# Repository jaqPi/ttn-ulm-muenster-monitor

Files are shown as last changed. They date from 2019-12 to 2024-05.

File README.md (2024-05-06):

# Sensor/Node für's Münster-Monitoring

Aktuell im Test, Messaufbau und ein paar Infos: https://wiki.temporaerhaus.de/risssimulator16153

## Pin-Belegung

```
Münster-Platine              VL6180X      BME280       Pull-Up-Widerstände
---------------              -------      ------       -------------------

A4    SDA / Daten            4 / SDA      4 / SDA      *
A5    SCL / Takt             5 / SCL      3 / SCL      |   *
VCC   Versorgungsspannung    2 / VIN      1 / VIN      *   *
GND                          3 / GND      2 / GND
```

```
Adafruit Feather M0          VL6180X      BME280       Pull-Up-Widerstände
-------------------          -------      ------       -------------------

SDA    SDA / Daten           4 / SDA      4 / SDA      *
SCL    SCL / Takt            5 / SCL      3 / SCL      |   *
VCC   Versorgungsspannung    2 / VIN      1 / VIN      *   *
GND                          3 / GND      2 / GND
```

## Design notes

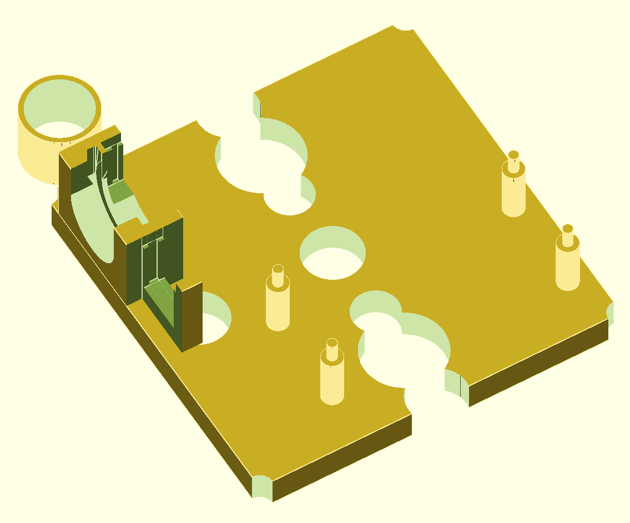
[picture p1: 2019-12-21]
3d-models/grundplatte_mit_halterungen.png

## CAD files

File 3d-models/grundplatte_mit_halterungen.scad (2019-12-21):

// Grundplatte mit Halterungen, für den Sensor des Münster-Monitorings

// mm

// X Position x-Achse
// Y Position y-Achse
// B Breite x-Achse
// H Höhe   z-Achse
// T Tiefe  y-Achse
// R Radius
// D Durchmesser


$fa = 0.1;
$fs = 0.1;

// PARAMETRIERUNG

e           = 0.4;  // Luft für Ungenauigkeiten des Druckers.


//Grundplatte gp mit Bohrungen:
gpUrsprX    = 0;
gpUrsprY    = 0;

gpB         = 70;
gpH         = 70;
gpT         = 6.2; //6.2

gpBohrungAktiv =  true;
gpBohrungX  = 0;
gpBohrungY  = 0;
gpBohrungD  = 5;
gpBohrungB  = gpB;//gpB - 2 * gpBohrungX;
gpBohrungH  = gpH;//gpH - 2 * gpBohrungY;


// Pins für Mikro-Controller pc:
pcX         = 20;  // Position Mittelpunkt Pin links unten
pcY         = 10;
// Maße für den Adafruit Feather:
pcB         = 45.6;  // Abstand Mittelpunkte Pins in x-Richtung
pcH         = 17.6;  // Abstand Mittelpunkte Pins in x-Richtung

pcBasisD    = 4;
pcBasisT    = 7 + 4 + gpT; // 7 mm für Dicke Akku, 4 mm Luft
pcPinD      = 2.5 - 1.5 * e;
pcPinT      = 4  + pcBasisT;  // Dicke PCB Feather ~ 1,6 mm



// Röhre als Durchlass r:

rH          = 12;
rDAussen    = 14;
rDickeWand  = 1;
rBasisD     = 4 + rDAussen;
rBasisH     = 1.0;
rHoeheUnterkanteBasisDUeberGP = 0;

// Scheibe zum Abschluss der Röhre s:

sDicke      = 1;
rHalterungBasisH = rBasisH + sDicke + 1.5 * e;
rHalterungBasisH = sDicke + 1.5 * e;


// Break out boards bob:

bobHoeheUnterkanteUeberGP = 4;
bobSteckerT = 2.6;
babAbstaendeInHalterung = 2;


// BME280, Billo-Breakoutboard bobBME280:

bobBME280Breite             = 10.5 + e;
bobBME280Dicke              = 1.55 + e; // Dicke PCB bobBME280 ~ 1,57 mm
bobBME280HoeheBisStecker    = 11;
bobBME280TiefeFuge          = 1 - e;
bobVME280X                  = 4;      // relativ zum Sensorhalterblock
//bobVME280Y                = bobVL6180XY + bobVL6180XBreite + babAbstaendeInHalterung;
bobVME280Y                  = babAbstaendeInHalterung + 0;
bobVME280Z                  = gpT + bobHoeheUnterkanteUeberGP - (gpT - 1) - 1;


// VL6180X, Pololu-Breakoutboard bobVL6180X:

bobVL6180XBreite            = 17.8 + e;
bobVL6180XDicke             = 0.9 + e;
bobVL6180XHoeheBisStecker   = 10;
bobVL6180XHoehe             = bobVL6180XHoeheBisStecker + bobSteckerT;
bobVL6180XTiefeFuge         = 1 - e ;       // Dicke PCB bobVL6180X ~ 1 mm
bobVL6180XX                 = 9;
//bobVL6180XY               = babAbstaendeInHalterung + 0;
bobVL6180XY                 = bobVME280Y + bobBME280Breite + babAbstaendeInHalterung;
bobVL6180XZ                 = gpT + bobHoeheUnterkanteUeberGP - (gpT - 1);


// Block, um in der Sensorhalterung Aussparungen für die Stecker zu schaffen

mBreakoutboardSteckerBlockT = 10;
mBreakoutboardSteckerBlockB = 20;
mBreakoutboardSteckerBlockOffsetX = -2; // Für Überstand Pins/Lötkegel


// Block für Halterung der Sensoren sb:

sbB     = 11;
sbH     = bobVL6180XBreite + bobBME280Breite + 3 * babAbstaendeInHalterung;
sbT     = gpT + bobHoeheUnterkanteUeberGP + bobVL6180XHoehe - (gpT - 1);
sbX     = 0;
sbY     = 48 - ( 2 * ( 2 + e ) + bobBME280Breite + (rBasisD - rDAussen) / 2);
sbZ     = gpT - 0.2;






// AUFBAU


// Grundplatte mit Pins:

module bohrung (x, y, z = 0,
                h = gpT * 4, d = gpBohrungD, centered = true
                ) {
    translate([x, y, z]) {
        cylinder(h = h, d = d, center = centered);
    }
}

module pin (x, y, z = 0) {
    translate([x, y, z]) {
        union () {
            cylinder(h = pcBasisT, d = pcBasisD);
            cylinder(h = pcPinT, d = pcPinD);
        }
    }
}


difference () {

    cube([gpB, gpH, gpT]);

    if (gpBohrungAktiv) {
        bohrung(gpBohrungX             , gpBohrungY);
        bohrung(gpBohrungX + gpBohrungB, gpBohrungY);
        bohrung(gpBohrungX             , gpBohrungY + gpBohrungH);
        bohrung(gpBohrungX + gpBohrungB, gpBohrungY + gpBohrungH);
    }
    
    bohrung(x = 35, y = 1, d = 10 + 3 * e);
    bohrung(x = 35, y = 70 - 1, d = 10 + 3 * e);
    translate([35, 0, 0]) {
        cube([10 + 2 * e, (10 + 3 * e) / 2, gpT * 4], center = true);
    }
    translate([35, 70, 0]) {
        cube([10 + 2 * e, (10 + 3 * e) / 2, gpT * 4], center = true);
    }
    
    bohrung(x = 35, y = 5 + 6.8,          d = 15 + e);
    bohrung(x = 35, y = 70 - (5 + 6.8),   d = 15 + e);
    
    bohrung(x = 35, y = 35 - 14, d = 7.5 + 3 * e);
    bohrung(x = 35, y = 35 + 14, d = 7.5 + 3 * e);
    
    bohrung(x = 35,         y = 35, d = 10.2 + 2 * e);
    bohrung(x = 35 - 26,    y = 35, d = 10.2 + 2 * e);
    
    translate ([14, 14 ,-1]) {
        cube([12, 13, 2 + 1]);
        translate ([0, 29 , 0]) {
            cube([12, 13, 2 + 1]);
        }
    }
    
}

pin(pcX      , pcY);
pin(pcX + pcB, pcY);
pin(pcX      , pcY + pcH);
pin(pcX + pcB, pcY + pcH);



// Röhre

module roehre ( x, y, z, 
                hoehe,
                durchmesserAussen,
                dickeWand,
                basisDurchmesser,
                basisHoehe,
                gefuellt = false,
                basis = true) {

    zentriert = true;
    translate([x, y, z]) {
        difference () {
            union () {
                translate ([0, 0, hoehe / 2]) {
                    cylinder(h = hoehe, d = durchmesserAussen, center = zentriert);
                }
                if (basis) {
                    translate ([0, 0, basisHoehe / 2]) {
                        cylinder(h = basisHoehe, d = basisDurchmesser, center = zentriert);
                    }
                }
            }
            if (! gefuellt) {
                cylinder(h = hoehe * 4, d = durchmesserAussen - 2 * dickeWand, center = zentriert);
            }
        }
    }
}



module roehreAussparung () {
    translate ([0, rBasisD / 2, rBasisD / 2 + rHoeheUnterkanteBasisDUeberGP]) {
    union () {
        linear_extrude (20) {
            projection () {
                rotate ([0, -90, 0 ]) {
                    roehre (0, 0, 0,
                            rH, rDAussen, rDickeWand, rBasisD, rHalterungBasisH,
                            gefuellt = true);
                }
            }
        }
        rotate ([0, -90, 0 ]) {
            roehre (0, 0, 0,
                    rH, rDAussen, rDickeWand, rBasisD, rHalterungBasisH,
                    gefuellt = true);
        }
    }
}
}

roehre (rBasisD / 2, gpH + rBasisD / 2 + 1 , 0,
        rH, rDAussen, rDickeWand, rBasisD, rBasisH,
        gefuellt = false, basis = false);

//roehre (rBasisD * 1.5, gpH + rBasisD / 2 + 1 , 0,
//        rH, rDAussen, rDickeWand, rBasisD, rBasisH,
//        gefuellt = false);




// Sensorhalterung

module breakoutboard (breite, dicke, hoeheBisStecker, breiteFuge, x, y, z) {
    translate ([x, y, z]) {
    union () {
        cube([dicke, breite, hoeheBisStecker+mBreakoutboardSteckerBlockT]);
        translate ([mBreakoutboardSteckerBlockOffsetX, 0, hoeheBisStecker]) {
            cube([mBreakoutboardSteckerBlockB, breite, mBreakoutboardSteckerBlockT]);
        }
        translate ([mBreakoutboardSteckerBlockOffsetX, breiteFuge, 0]) {
            cube([  mBreakoutboardSteckerBlockB,
                    breite - 2 * breiteFuge,
                    hoeheBisStecker + mBreakoutboardSteckerBlockT
            ]);
        }
    }
    }
}


translate([sbX, sbY, sbZ]) {
difference () {
    
    cube([sbB, sbH, sbT]);
    
    breakoutboard(bobVL6180XBreite, bobVL6180XDicke, bobVL6180XHoeheBisStecker, bobVL6180XTiefeFuge, bobVL6180XX, bobVL6180XY, bobVL6180XZ);
    
    breakoutboard(bobBME280Breite, bobBME280Dicke, bobBME280HoeheBisStecker, bobBME280TiefeFuge, bobVME280X, bobVME280Y, bobVME280Z);    
    
    translate ([bobVL6180XX - ( 1 + abs(mBreakoutboardSteckerBlockOffsetX)) ,
                bobVL6180XY + (bobVL6180XBreite - rBasisD) / 2 ,
                1
                ]) {
        roehreAussparung ();
        translate ([-rHalterungBasisH, rBasisD, 0]) {
            rotate ([180, 180, 0]) {
                roehreAussparung ();
            }
        }

    }
    
    // Materialeinsparungen:
    translate([-1 , bobVME280Y - babAbstaendeInHalterung - e, -1]) {
        cube([  bobVME280X + mBreakoutboardSteckerBlockOffsetX + 2.01,
                bobBME280Breite + babAbstaendeInHalterung + 0.01 + e,
                sbT * 2
            ]);
        translate([8, 0, -1]) {
            cube([  bobVME280X + mBreakoutboardSteckerBlockOffsetX + 3.01,
                bobBME280Breite + babAbstaendeInHalterung + 0.01 + e,
                sbT * 2
            ]);
        }
    }
    
}
}

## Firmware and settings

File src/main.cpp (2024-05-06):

/*
Code is based on the the OTAA example of the arduino-lmic library

 * Copyright (c) 2015 Thomas Telkamp and Matthijs Kooijman
 * Copyright (c) 2018 Terry Moore, MCCI

which is licensed under the MIT license
https://github.com/mcci-catena/arduino-lmic/blob/master/examples/ttn-otaa/ttn-otaa.ino
*/

#include "arduino_lmic.h"
#include <hal/hal.h>
#include <Wire.h>
#include <SPI.h>
#include <Adafruit_Sensor.h>
#include <Adafruit_BME280.h>
#include <VL6180X.h>
#include "measurements.h"
#include "sensors.h"
#include <Statistics.h>


#include <Credentials.h> // TODO

// #define SINGLE_VALUES
const uint8_t numberOfMeasurements = 50; // max 255!

VL6180X sensorVL6180X;
const SensorConfig configInterleaved = { INTERLEAVED, MANUAL, 30, 50, 500};
const TofSensor tofSensor = TofSensor { sensorVL6180X, configInterleaved, 0, 0x29 };

#ifdef DEBUG
  #define print(x) Serial.print(x);
  #define println(x) Serial.println(x);
#else
  #define print(x)
  #define println(x)
#endif

Adafruit_BME280 bme; // I2C, depending on your BME, you have to use address 0x77 (default) or 0x76, see below


// These callbacks are only used in over-the-air activation, so they are
// left empty here (we cannot leave them out completely unless
// DISABLE_JOIN is set in arduino-lmic/project_config/lmic_project_config.h,
// otherwise the linker will complain).
void os_getArtEui (u1_t* buf) { memcpy_P(buf, APPEUI, 8);}
void os_getDevEui (u1_t* buf) { memcpy_P(buf, DEVEUI, 8);}
void os_getDevKey (u1_t* buf) {  memcpy_P(buf, APPKEY, 16);}

static osjob_t sendjob;

const unsigned TX_INTERVAL = 5*60; // in seconds
const int SLEEP_CYCLES = (int) (TX_INTERVAL / 8);


// Pin mapping
#ifdef MINSTER_NODE
// Pin mapping for Minster Node
const lmic_pinmap lmic_pins = {
        .nss = 10, // ulm node 10
        .rxtx = LMIC_UNUSED_PIN,
        .rst = LMIC_UNUSED_PIN,
        .dio = {4, 5, 6}, // TTN Ulm Minster node {4, 5 ,6}
};
#elif FEATHER_M0
// Pin mapping for Adafruit Feather M0 LoRa
const lmic_pinmap lmic_pins = {
    .nss = 8,
    .rxtx = LMIC_UNUSED_PIN,
    .rst = 4,
    .dio = {3, 6, LMIC_UNUSED_PIN},
    .rxtx_rx_active = 0,
    .rssi_cal = 8,              // LBT cal for the Adafruit Feather M0 LoRa, in dB
    .spi_freq = 8000000,
};
#endif

void printValues() {
    // print("Temperature = ");
    // print(bme.readTemperature());
    // println(" *C");

    // print("Pressure = ");

    // print(bme.readPressure());
    // println(" hPa");

    // print("Humidity = ");
    // print(bme.readHumidity());
    // println(" %");

    // println();
}

float measureBatteryVoltage() {
    float measuredvbat = analogRead(A0);
    measuredvbat *= 2;    // we divided by 2, so multiply back
    measuredvbat *= 3.3;  // Multiply by 3.3V, our reference voltage
    measuredvbat /= 1024; // convert to voltage
    return measuredvbat;
}

void do_send(osjob_t* j){
    // Check if there is not a current TX/RX job running
    if (LMIC.opmode & OP_TXRXPEND) {
      println(F("OP_TXRXPEND, not sending"));
    } else {
        // temp -> 2 byte
        // pressure -> 2 byte
        // humidity -> 2 byte
        // distance -> 2 byte
        // distanceMedian -> 2 byte
        // distanceSD -> 2 byte
        // distanceSucc -> 1 byte
        // ambientLight -> 2 byte
        // ambientLightMedian -> 2 byte
        // ambientLightSD -> 2 byte
        // ambietnLightSucc -> 1 byte
        // batteryVoltage -> 2 byte

        // sum -> 22 byte
        byte payload[22];

        // Only needed in forced mode. Force update of BME values
        bme.takeForcedMeasurement();

        #ifdef DEBUG
          printValues();
        #endif

        // temp
        int temp = round(bme.readTemperature() * 100);
        payload[0] = highByte(temp);
        payload[1] = lowByte(temp);

        // pressure
        int pressure = round(bme.readPressure()/100);
        payload[2] = highByte(pressure);
        payload[3] = lowByte(pressure);

        // humidity
        int humidity = round(bme.readHumidity() * 100);
        payload[4] = highByte(humidity);
        payload[5] = lowByte(humidity);

        measurement_t currentMeasurement = measureDistanceAndAmbientLight(&tofSensor, numberOfMeasurements);

        // distance
        int meanDistance = round(currentMeasurement.distance.mean * 100);
        payload[6] = highByte(meanDistance);
        payload[7] = lowByte(meanDistance);

        int standardDeviationDistance = round(currentMeasurement.distance.standardDeviation * 100);
        payload[8] = highByte(standardDeviationDistance);
        payload[9] = lowByte(standardDeviationDistance);

        int medianDistance = round(currentMeasurement.distance.median * 100);
        payload[10] = highByte(medianDistance);
        payload[11] = lowByte(medianDistance);

        payload[12] = currentMeasurement.successfulMeasurementsDistance;

        // ambientLight
        int meanAmbientLight = round(currentMeasurement.light.mean * 100);
        payload[13] = highByte(meanAmbientLight);
        payload[14] = lowByte(meanAmbientLight);

        int standardDeviationAmbientLight = round(currentMeasurement.light.standardDeviation * 100);
        payload[15] = highByte(standardDeviationAmbientLight);
        payload[16] = lowByte(standardDeviationAmbientLight);

        int medianLight = round(currentMeasurement.light.median * 100);
        payload[17] = highByte(medianLight);
        payload[18] = lowByte(medianLight);

        payload[19] = currentMeasurement.successfulMeasurementsAmbientLight;

        //int batteryVoltage = round(measureBatteryVoltage() * 100);
        // temporary set battery voltage to zero
        int batteryVoltage = 0;
        payload[20] = highByte(batteryVoltage);
        payload[21] = lowByte(batteryVoltage);


        LMIC_setTxData2(1, (uint8_t*)payload, sizeof(payload), 0);
        println(F("Pckt qd"));
    }
}

void onEvent (ev_t ev) {
    // print(os_getTime());
    // print(": ");
    print(os_getTime());
    println(": ");
    switch(ev) {
#ifndef MINSTER_NODE
        case EV_SCAN_TIMEOUT:
            println(F("EV_SCAN_TIMEOUT"));
            break;
        case EV_BEACON_FOUND:
            println(F("EV_BEACON_FOUND"));
            break;
        case EV_BEACON_MISSED:
            println(F("EV_BEACON_MISSED"));
            break;
        case EV_BEACON_TRACKED:
            println(F("EV_BEACON_TRACKED"));
            break;
        case EV_JOINING:
            println(F("EV_JOINING"));
            break;
        case EV_JOINED:
            println(F("EV_JOINED"));
            break;
        /*
        || This event is defined but not used in the code. No
        || point in wasting codespace on it.
        ||
        || case EV_RFU1:
        ||     Serial.println(F("EV_RFU1"));
        ||     break;
        */
        case EV_JOIN_FAILED:
            println("EV_JOIN_FAILED");
            break;
        case EV_REJOIN_FAILED:
            println("EV_REJOIN_FAILED");
            break;
#endif
        case EV_TXCOMPLETE:
            println("EV_TXCOMPLETE");
#ifndef MINSTER_NODE
            if (LMIC.txrxFlags & TXRX_ACK)
              println("Rcvd ack");
            if (LMIC.dataLen) {
              println("Received ");
              println(LMIC.dataLen);
              println(" bytes of payload");
            }
#endif
            // println(F("EV_TXCOMPLETE"));
            // if (LMIC.txrxFlags & TXRX_ACK)
            //     println(F("Received ack"));
            // if (LMIC.dataLen) {
            //     println(F("Received "));
            //     println(LMIC.dataLen);
            //     println(F(" bytes of payload"));
            // }

            // Now preparing to go into sleep mode. The LMIC library already
            // powers down the RFM95, see
            // https://www.thethingsnetwork.org/forum/t/how-to-put-rfm95-to-sleep/9427

            // Following code is adapted by
            // https://github.com/rocketscream/MiniUltraPro/blob/master/ttn-otaa-sleep.ino

            // Ensure all debugging messages are sent before sleep
            #ifdef DEBUG
              Serial.flush();
            #endif

            // Going into sleep for more than 8 s – any better idea?
            // disabled due to sensor vulnerability to voltage
            //for(int i = 0; i < SLEEP_CYCLES; i++) {
            //  LowPower.powerDown(SLEEP_8S, ADC_OFF, BOD_OFF);
            //}

            // Schedule next transmission to be immediately after this
            os_setTimedCallback(&sendjob, os_getTime() + sec2osticks(TX_INTERVAL), do_send);

            break;
#ifndef MINSTER_NODE
        case EV_LOST_TSYNC:
            println(F("EV_LOST_TSYNC"));
            break;
        case EV_RESET:
            println(F("EV_RESET"));
            break;
        case EV_RXCOMPLETE:
            // data received in ping slot
            println(F("EV_RXCOMPLETE"));
            break;
        case EV_LINK_DEAD:
            println(F("EV_LINK_DEAD"));
            break;
        case EV_LINK_ALIVE:
            println(F("EV_LINK_ALIVE"));
            break;
        /*
        || This event is defined but not used in the code. No
        || point in wasting codespace on it.
        ||
        || case EV_SCAN_FOUND:
        ||    Serial.println(F("EV_SCAN_FOUND"));
        ||    break;
        */
        case EV_TXSTART:
            println(F("EV_TXSTART"));
            break;
        case EV_TXCANCELED:
            println(F("EV_TXCANCELED"));
            break;
        case EV_RXSTART:
            /* do not print anything -- it wrecks timing */
            break;
        case EV_JOIN_TXCOMPLETE:
            println(F("EV_JOIN_TXCOMPLETE: no JoinAccept"));
            break;
        default:
            print(F("Unknown event: "));
            println((unsigned) ev);
            break;
#endif
    }
}

void scanI2C() {
  println("I2C scanner. Scanning ...");
  byte count = 0;


  for (byte i = 1; i < 120; i++)
  {

    Wire.beginTransmission (i);
    if (Wire.endTransmission () == 0)
    {
      print("Found address: ");
      print(i);
      print(" (0x");
      print(i);
      println(")");
      count++;
      delay (1);  // maybe unneeded?
    } // end of good response
  } // end of for loop
  println("Done.");
  print("Found ");
  print(count);
  println(" device(s).");
}

void setup() {
    #ifdef DEBUG
      Serial.begin(9600);
      while(!Serial);
    #endif
    println(F("Strtng"));

    Wire.begin();
    delay(5000);



    // Switch off on board LED
    pinMode(LED_BUILTIN, OUTPUT);
    digitalWrite(LED_BUILTIN, LOW);

    #ifdef DEBUG
      scanI2C();
    #endif
    

    // Setup BME280, use address 0x77 (default) or 0x76
    if (!bme.begin(0x76)) {
      println(F("noBME"));
      while (1);
    }

    // Set BME in force mode to reduce power consumption
    // force mode = measure, store results, and go into sleep mode
    // until next measurement, see
    // - http://tinkerman.cat/low-power-weather-station-bme280-moteino/
    // - https://github.com/adafruit/Adafruit_BME280_Library/blob/master/examples/advancedsettings/advancedsettings.ino
    bme.setSampling(Adafruit_BME280::MODE_FORCED,
                    Adafruit_BME280::SAMPLING_X1, // temperature
                    Adafruit_BME280::SAMPLING_X1, // pressure
                    Adafruit_BME280::SAMPLING_X1, // humidity
                    Adafruit_BME280::FILTER_OFF   );


      tofSensor.sensor.init();
      tofSensor.sensor.configureDefault();

      // Reduce range max convergence time and ALS integration
      // time to 30 ms and 50 ms, respectively, to allow 10 Hz
      // operation (as suggested by table "Interleaved mode
      // limits (10 Hz operation)" in the datasheet).
      tofSensor.sensor.writeReg(VL6180X::SYSRANGE__MAX_CONVERGENCE_TIME, tofSensor.config.rangeMaxConvergenceTime);
      tofSensor.sensor.writeReg16Bit(VL6180X::SYSALS__INTEGRATION_PERIOD, tofSensor.config.alsMaxIntegrationPeriod);
      tofSensor.sensor.setTimeout(tofSensor.config.timeout);

      // stop continuous mode if already active
      tofSensor.sensor.stopContinuous();
      // in case stopContinuous() triggered a single-shot
      // measurement, wait for it to complete
      delay(300);

      if(tofSensor.config.calibrationMode == MANUAL) {
        // disable auto calibrate (to do it manually before every series)
        tofSensor.sensor.writeReg(VL6180X::SYSRANGE__VHV_REPEAT_RATE, 0x00);    
        // calibrate single time (actually the sensor should have done it during start up)
        tofSensor.sensor.writeReg(VL6180X::SYSRANGE__VHV_RECALIBRATE, 0x01);   
      }

      println(", configuration completed");

     // LMIC init
    os_init();
    // Reset the MAC state. Session and pending data transfers will be discarded.
    LMIC_reset();


    LMIC_setClockError(MAX_CLOCK_ERROR * 20 / 100);

    // Disable link check validation
    LMIC_setLinkCheckMode(0);

    // TTN uses SF9 for its RX2 window.
    LMIC.dn2Dr = DR_SF9;

    // Set data rate and transmit power for uplink
    LMIC_setDrTxpow(DR_SF7,14);

    // Start job
    do_send(&sendjob);
}

void loop() {
    os_runloop_once();
}

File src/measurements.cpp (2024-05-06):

#include "measurements.h"

measurement_t measureDistanceAndAmbientLight(const TofSensor *tofSensor, uint8_t numberOfMeasurements) {
    if(tofSensor->config.measureMode == INTERLEAVED) {
        return measureDistanceAndAmbientLightInterleaved(tofSensor, numberOfMeasurements);
    }
    else {
        return measureDistanceAndAmbientLightOneByOne(tofSensor, numberOfMeasurements);
    }
}

measurement_t measureDistanceAndAmbientLightInterleaved(const TofSensor *tofSensor, uint8_t numberOfMeasurements) {
    uint16_t measurementSeriesDistance[numberOfMeasurements];
    uint16_t measurementSeriesAmbientLight[numberOfMeasurements];

    Serial.print("Start interleaved measurement using ToF-Sensor ");
    Serial.print(tofSensor->i2cAddress);
    Serial.print(", #Measurement: ");
    Serial.println(numberOfMeasurements);

    // calibrate sensor in terms of temperature manually
    if(tofSensor->config.calibrationMode == MANUAL) {
        tofSensor->sensor.writeReg(VL6180X::SYSRANGE__VHV_RECALIBRATE, 0x01);    
    }


    tofSensor->sensor.startInterleavedContinuous();
    uint8_t successfulMeasurementsDistance = 0;
    uint8_t successfulMeasurementsAmbientLight = 0;

    for (uint8_t i = 0; i < numberOfMeasurements; i++) {
        // Ambient Light
        uint16_t currentAmbientLight = tofSensor->sensor.readAmbientContinuous();
        if (!tofSensor->sensor.timeoutOccurred()) {
            measurementSeriesAmbientLight[successfulMeasurementsAmbientLight] = currentAmbientLight;
            successfulMeasurementsAmbientLight += 1;

            #ifdef SINGLE_VALUES
                // Print current value to Serial
                if(i == numberOfMeasurements - 1) {
                    Serial.println(currentAmbientLight);
                }
                else {
                    Serial.print(currentAmbientLight);
                    Serial.print(",");
                }
            #endif
        }

        // Distance
        uint16_t currentDistance = (uint16_t) tofSensor->sensor.readRangeContinuous();
        if (!tofSensor->sensor.timeoutOccurred()) {
            measurementSeriesDistance[successfulMeasurementsDistance] = currentDistance;
            successfulMeasurementsDistance += 1;

            #ifdef SINGLE_VALUES
                // Print current value to Serial
                if(i == numberOfMeasurements - 1) {
                    Serial.println(currentDistance);
                }
                else {
                    Serial.print(currentDistance);
                    Serial.print(",");
                }
            #endif
        }
    }
    tofSensor->sensor.stopContinuous();

    stats_t statsAmbientLight = calcStats(successfulMeasurementsAmbientLight, measurementSeriesAmbientLight, numberOfMeasurements);
    stats_t statsDistance = calcStats(successfulMeasurementsDistance, measurementSeriesDistance, numberOfMeasurements);



    Serial.print("DistSucc: ");
    Serial.print(successfulMeasurementsDistance);
    Serial.print("/");
    Serial.print(numberOfMeasurements);
    Serial.println();

    Serial.print("DistM: ");
    Serial.print(statsDistance.mean);
    Serial.println();

    Serial.print("DistMD: ");
    Serial.print(statsDistance.median);
    Serial.println();

    Serial.print("DistSD: ");
    Serial.print(statsDistance.standardDeviation);
    Serial.println();


    Serial.print("ALSsuc: ");
    Serial.print(successfulMeasurementsAmbientLight);
    Serial.print("/");
    Serial.print(numberOfMeasurements);
    Serial.println();

    Serial.print("ALSM: ");
    Serial.print(statsAmbientLight.mean);
    Serial.println();

    Serial.print("ALSMD: ");
    Serial.print(statsAmbientLight.median);
    Serial.println();

    Serial.print("ALSSD: ");
    Serial.print(statsAmbientLight.standardDeviation);
    Serial.println();

	measurement_t measurement = { statsDistance, statsAmbientLight, successfulMeasurementsDistance, successfulMeasurementsAmbientLight };

  return measurement;
}

measurement_t measureDistanceAndAmbientLightOneByOne(const TofSensor *tofSensor, uint8_t numberOfMeasurements) {
    uint16_t measurementSeriesDistance[numberOfMeasurements];
    uint16_t measurementSeriesAmbientLight[numberOfMeasurements];

    Serial.print("Start ony-by-one measurement using ToF-Sensor ");
    Serial.print(tofSensor->i2cAddress);
    Serial.print(", #Measurement: ");
    Serial.println(numberOfMeasurements);

    // calibrate sensor in terms of temperature manually
    if(tofSensor->config.calibrationMode == MANUAL) {
        tofSensor->sensor.writeReg(VL6180X::SYSRANGE__VHV_RECALIBRATE, 0x01);    
    }


    tofSensor->sensor.startAmbientContinuous();
    uint8_t successfulMeasurementsAmbientLight = 0;

    for (uint8_t i = 0; i < numberOfMeasurements; i++) {
        // Ambient Light
        uint16_t currentAmbientLight = tofSensor->sensor.readAmbientContinuous();
        if (!tofSensor->sensor.timeoutOccurred()) {
            measurementSeriesAmbientLight[successfulMeasurementsAmbientLight] = currentAmbientLight;
            successfulMeasurementsAmbientLight += 1;

            #ifdef SINGLE_VALUES
                // Print current value to Serial
                if(i == numberOfMeasurements - 1) {
                    Serial.println(currentAmbientLight);
                }
                else {
                    Serial.print(currentAmbientLight);
                    Serial.print(",");
                }
            #endif
        }
    }
    tofSensor->sensor.stopContinuous();
    delay(300);


    tofSensor->sensor.startRangeContinuous();
    uint8_t successfulMeasurementsDistance = 0;
    for (uint8_t i = 0; i < numberOfMeasurements; i++) {
        // Distance
        uint16_t currentDistance = (uint16_t) tofSensor->sensor.readRangeContinuous();
        if (!tofSensor->sensor.timeoutOccurred()) {
            measurementSeriesDistance[successfulMeasurementsDistance] = currentDistance;
            successfulMeasurementsDistance += 1;

            #ifdef SINGLE_VALUES
                // Print current value to Serial
                if(i == numberOfMeasurements - 1) {
                    Serial.println(currentDistance);
                }
                else {
                    Serial.print(currentDistance);
                    Serial.print(",");
                }
            #endif
        }
    }
    tofSensor->sensor.stopContinuous();
    delay(300);

    stats_t statsAmbientLight = calcStats(successfulMeasurementsAmbientLight, measurementSeriesAmbientLight, numberOfMeasurements);
    stats_t statsDistance = calcStats(successfulMeasurementsDistance, measurementSeriesDistance, numberOfMeasurements);

    Serial.print("DistSucc: ");
    Serial.print(successfulMeasurementsDistance);
    Serial.print("/");
    Serial.print(numberOfMeasurements);
    Serial.println();

    Serial.print("DistM: ");
    Serial.print(statsDistance.mean);
    Serial.println();
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

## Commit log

2019-11-12 add distance sensor
2019-11-23 README.md angelegt; Pin-Belegung eingefügt.
2019-11-24 add measurement of battery voltage
2019-11-25 TTN-Payload-Decoder hinzugefügt; kleine Formatierungen und Schreibfehler.
2019-12-01 add manual temperature calibration of distance sensor
2019-12-08 3D-Modell für Sensorhalterung hinzugefügt (beta).
    [grundplatte_mit_halterungen.scad, grundplatte_mit_halterungen.stl]
2019-12-08 3D-Model: Werte und Renderung für ersten Druck.
    [grundplatte_mit_halterungen.scad, grundplatte_mit_halterungen.stl]
2019-12-08 disable auto calibration
2019-12-21 Grundplatte: Weiterentwickelt.
    [grundplatte_mit_halterungen.scad, grundplatte_mit_halterungen.stl]
2020-07-05 Pin-Belegung für Adafruit Feather M0 hinzugefügt.
2020-08-13 add missing minster node pin mapping and replace deprecated platformio env var
    [main.cpp]
2021-09-12 - update lib deps - switch from abp to otaa - extend sent statistics by median
2021-10-19 switch off internal LED
